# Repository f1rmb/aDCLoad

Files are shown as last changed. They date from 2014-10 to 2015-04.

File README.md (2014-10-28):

Arduino Programmable Constant Current Power Resistance Load
===========================================================

This is all of the code, datasheets and design files for [my instructable](http://www.instructables.com/id/Arduino-Programmable-Constant-Current-Power-Resist/ "Arduino Programmable Constant Current Power Resistance Load") 

* Arduino - It contains the Arduino code that we will be talking about here, within the dummy load folder. It also contains all of the 3rd party libraries I have used.
* Datasheets - It contains all of the datasheets for the major components used within the project.
* DesignSpark - I have used the opensource schematic and PCB design software for this project, its a fantastic free tool that has no limitations and I find it easier to uses than Eagle - http://www.rs-online.com/designspark/electronics/eng/page/designspark-pcb-home-page The rev 1 folder contains all of my initial designs, please don't use this as there are 2 or 3 errors in the footprints plus I have completely revised the layout for rev 2, please only use these files. the gerber files are in there should you wish to have your own board done. See the next step for more information on this.
* LTSpice - This contains all of the LtSpice files from simulating the operation of the MOSFET.

Please checkout my instructable as it describes all of this code and the operation of the dummy load.

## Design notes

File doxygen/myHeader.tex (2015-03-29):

\documentclass[twoside]{book}

% Packages required by doxygen
\usepackage{calc}
\usepackage{doxygen}
\usepackage{graphicx}
\usepackage[utf8]{inputenc}
\usepackage{makeidx}
\usepackage{multicol}
\usepackage{multirow}
\usepackage{textcomp}
\usepackage[table]{xcolor}

% Font selection
\usepackage[T1]{fontenc}
\usepackage{mathptmx}
\usepackage[scaled=.90]{helvet}
\usepackage{courier}
\usepackage{amssymb}
\usepackage{sectsty}
\renewcommand{\familydefault}{\sfdefault}
\allsectionsfont{%
  \fontseries{bc}\selectfont%
  \color{darkgray}%
}
\renewcommand{\DoxyLabelFont}{%
  \fontseries{bc}\selectfont%
  \color{darkgray}%
}

% Page & text layout
\usepackage{geometry}
\geometry{%
  a4paper,%
  top=2.5cm,%
  bottom=2.5cm,%
  left=2.5cm,%
  right=2.5cm%
}
\tolerance=750
\hfuzz=15pt
\hbadness=750
\setlength{\emergencystretch}{15pt}
\setlength{\parindent}{0cm}
\setlength{\parskip}{0.2cm}
\makeatletter
\renewcommand{\paragraph}{%
  \@startsection{paragraph}{4}{0ex}{-1.0ex}{1.0ex}{%
    \normalfont\normalsize\bfseries\SS@parafont%
  }%
}
\renewcommand{\subparagraph}{%
  \@startsection{subparagraph}{5}{0ex}{-1.0ex}{1.0ex}{%
    \normalfont\normalsize\bfseries\SS@subparafont%
  }%
}
\makeatother

% Headers & footers
\usepackage{fancyhdr}
\pagestyle{fancyplain}
\fancyhead[LE]{\fancyplain{}{\bfseries\thepage}}
\fancyhead[CE]{\fancyplain{}{}}
\fancyhead[RE]{\fancyplain{}{\bfseries\leftmark}}
\fancyhead[LO]{\fancyplain{}{\bfseries\rightmark}}
\fancyhead[CO]{\fancyplain{}{}}
\fancyhead[RO]{\fancyplain{}{\bfseries\thepage}}
\fancyfoot[LE]{\fancyplain{}{}}
\fancyfoot[CE]{\fancyplain{}{}}
\fancyfoot[RE]{\fancyplain{}{\bfseries\scriptsize User and Programmer Manual for aDCLoad 2.\-6, written by F1RMB Daniel Caujolle-Bert \copyright 2014-2015 }}
\fancyfoot[LO]{\fancyplain{}{\bfseries\scriptsize User and Programmer Manual for aDCLoad 2.\-6, written by F1RMB Daniel Caujolle-Bert \copyright 2014-2015 }}
\fancyfoot[CO]{\fancyplain{}{}}
\fancyfoot[RO]{\fancyplain{}{}}
\renewcommand{\footrulewidth}{0.4pt}
\renewcommand{\chaptermark}[1]{%
  \markboth{#1}{}%
}
\renewcommand{\sectionmark}[1]{%
  \markright{\thesection\ #1}%
}

% Indices & bibliography
\usepackage{natbib}
\usepackage[titles]{tocloft}
\setcounter{tocdepth}{3}
\setcounter{secnumdepth}{5}
\makeindex

% Hyperlinks (required, but should be loaded last)
\usepackage{ifpdf}
\ifpdf
  \usepackage[pdftex,pagebackref=true]{hyperref}
\else
  \usepackage[ps2pdf,pagebackref=true]{hyperref}
\fi
\hypersetup{%
  colorlinks=true,%
  linkcolor=blue,%
  citecolor=blue,%
  unicode%
}

% Custom commands
\newcommand{\clearemptydoublepage}{%
  \newpage{\pagestyle{empty}\cleardoublepage}%
}

%===== C O N T E N T S =====

\begin{document}

% Titlepage & ToC
\hypersetup{pageanchor=false}
\pagenumbering{roman}
\begin{titlepage}
\vspace*{7cm}
\begin{center}%
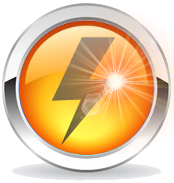
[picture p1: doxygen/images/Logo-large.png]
{}\\
\vspace*{0.5cm}
{\Large Manual for a\-D\-C\-Load \\[1ex]\large version 2.\-6 }\\
\vspace*{1cm}
{\large Written by F1RMB, Daniel Caujolle-Bert \copyright 2014-2015 }\\
\vspace*{1cm}
\end{center}
\end{titlepage}
\clearemptydoublepage
\tableofcontents
\clearemptydoublepage
\pagenumbering{arabic}
\hypersetup{pageanchor=true}

%--- Begin generated contents ---
\chapter{Arduino Programmable Constant Current Power Resistance Load}
\label{mainpage}
\hypertarget{mainpage}{}
\input{mainpage}
\chapter{A\-Tmega32\-U4 fuses settings}
\label{fuses}
\hypertarget{fuses}{}
\input{fuses}
\chapter{Hardware modifications for version 2.6}
\label{mods26}
\hypertarget{mods26}{}
\input{mods26}
\chapter{User interface overview}
\label{gui}
\hypertarget{gui}{}
\input{gui}
\chapter{Remote Commands}
\label{remote}
\hypertarget{remote}{}
\input{remote}
\chapter{Logging data format}
\label{logging}
\hypertarget{logging}{}
\input{logging}
\chapter{Calibration Process}
\label{calibration}
\hypertarget{calibration}{}
\input{calibration}
\chapter{Hierarchical Index}
\input{hierarchy}
\chapter{Class Index}
\input{annotated}
\chapter{File Index}
\input{files}
\chapter{Class Documentation}
\input{uniona_d_c_settings_1_1__eeprom_calibration_value__t}
\input{classa_d_c_display}
\input{classa_d_c_engine}
\input{classa_d_c_settings}
\input{classa_input_relay}
\input{classa_l_c_d}
\input{classa_stepper}
\input{structa_d_c_settings_1_1_calibration_data__t}
\chapter{File Documentation}
\input{a_d_c_load_8cpp}
\input{a_d_c_load_8h}
\input{_c_d_c_8cpp}
\input{_hardware_serial_8cpp}
\input{_h_i_d_8cpp}
\input{_i_p_address_8cpp}
\input{libraries_8cpp}
\input{main_8cpp}
\input{new_8cpp}
\input{_print_8cpp}
\input{sketch_8cpp}
\input{_stream_8cpp}
\input{_tone_8cpp}
\input{_u_s_b_core_8cpp}
\input{_w_interrupts_8c}
\input{wiring_8c}
\input{wiring__analog_8c}
\input{wiring__digital_8c}
\input{wiring__pulse_8c}
\input{wiring__shift_8c}
\input{_w_math_8cpp}
\input{_w_string_8cpp}
%--- End generated contents ---

% Index
\newpage
\phantomsection
\addcontentsline{toc}{chapter}{Index}
\printindex

\end{document}

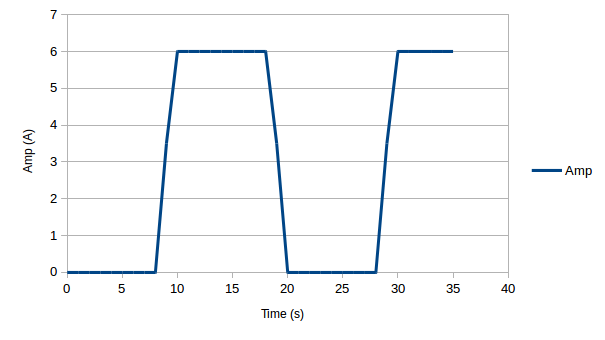
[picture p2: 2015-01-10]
doxygen/images/aDCLoad-Pulse.png

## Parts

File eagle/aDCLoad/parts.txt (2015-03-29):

Partlist

Exported from InputSwitch.brd at 10/02/15 17:02

EAGLE Version 6.1.0 Copyright (c) 1988-2012 CadSoft

Assembly variant: 

Part     Value              Package   Library                    Position (mm)         Orientation

C1       100nF              C0805     resistor                   (45.007634375 17.60451875) R270
D1                          SOD-123   adafruit                   (13.97 15.1765)       R90
H1       MOUNT-PAD-ROUND3.0 3,0-PAD   holes                      (-21.169 34.279)      R0
H2       MOUNT-PAD-ROUND3.0 3,0-PAD   holes                      (43.84 34.279)        R0
JP1      CTRL_PANEL         1X04      SparkFun-Connectors        (2.9381625 17.714425) R270
JP2      MCU                1X05      SparkFun-Connectors        (42.53510625 18.424425) R270
R1       10K                R0805     resistor                   (23.6855 16.9545)     R90
R2       10K                R0805     resistor                   (33.2105 14.224)      R90
R3       1k                 R0805     resistor                   (8.128 15.1765)       R0
R4       10k                R0805     resistor                   (44.96789375 11.736628125) R270
T1       PN2222             SOT23-3   SparkFun-DiscreteSemi      (28.067 16.0655)      R90
T2       PN2222             SOT23-3   SparkFun-DiscreteSemi      (19.558 17.018)       R90
U$1      RELAYPTH2          RELAY-T9A SparkFun-Electromechanical (24.13 13.97)         MR90

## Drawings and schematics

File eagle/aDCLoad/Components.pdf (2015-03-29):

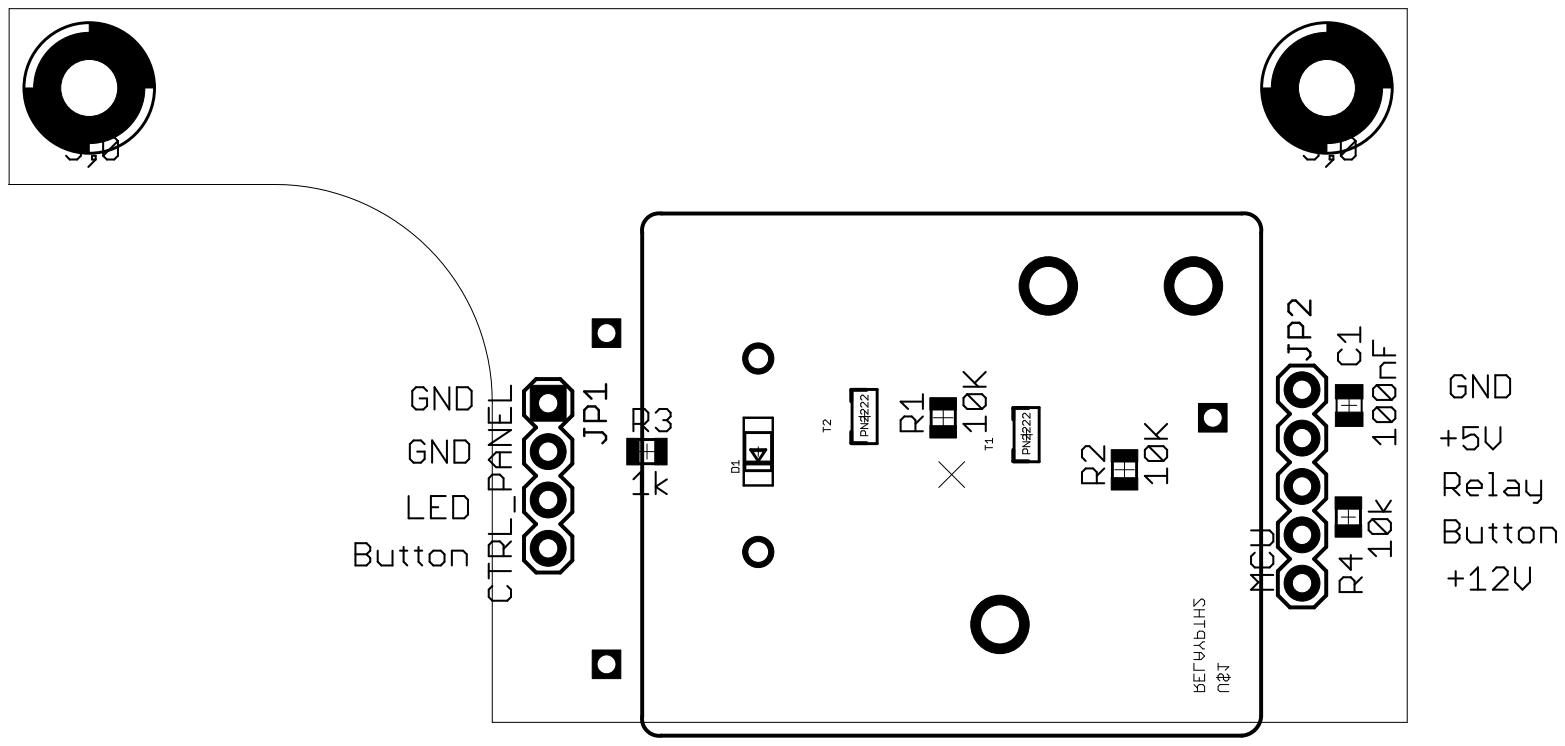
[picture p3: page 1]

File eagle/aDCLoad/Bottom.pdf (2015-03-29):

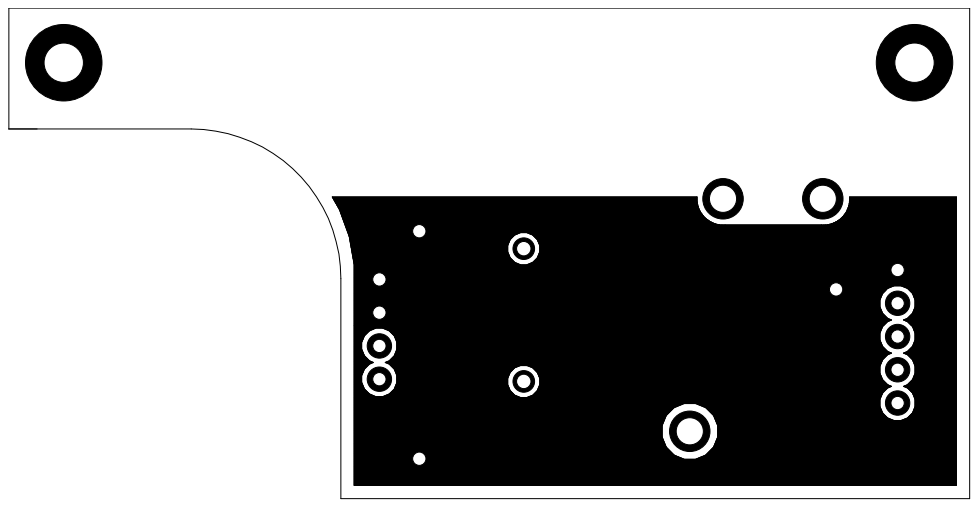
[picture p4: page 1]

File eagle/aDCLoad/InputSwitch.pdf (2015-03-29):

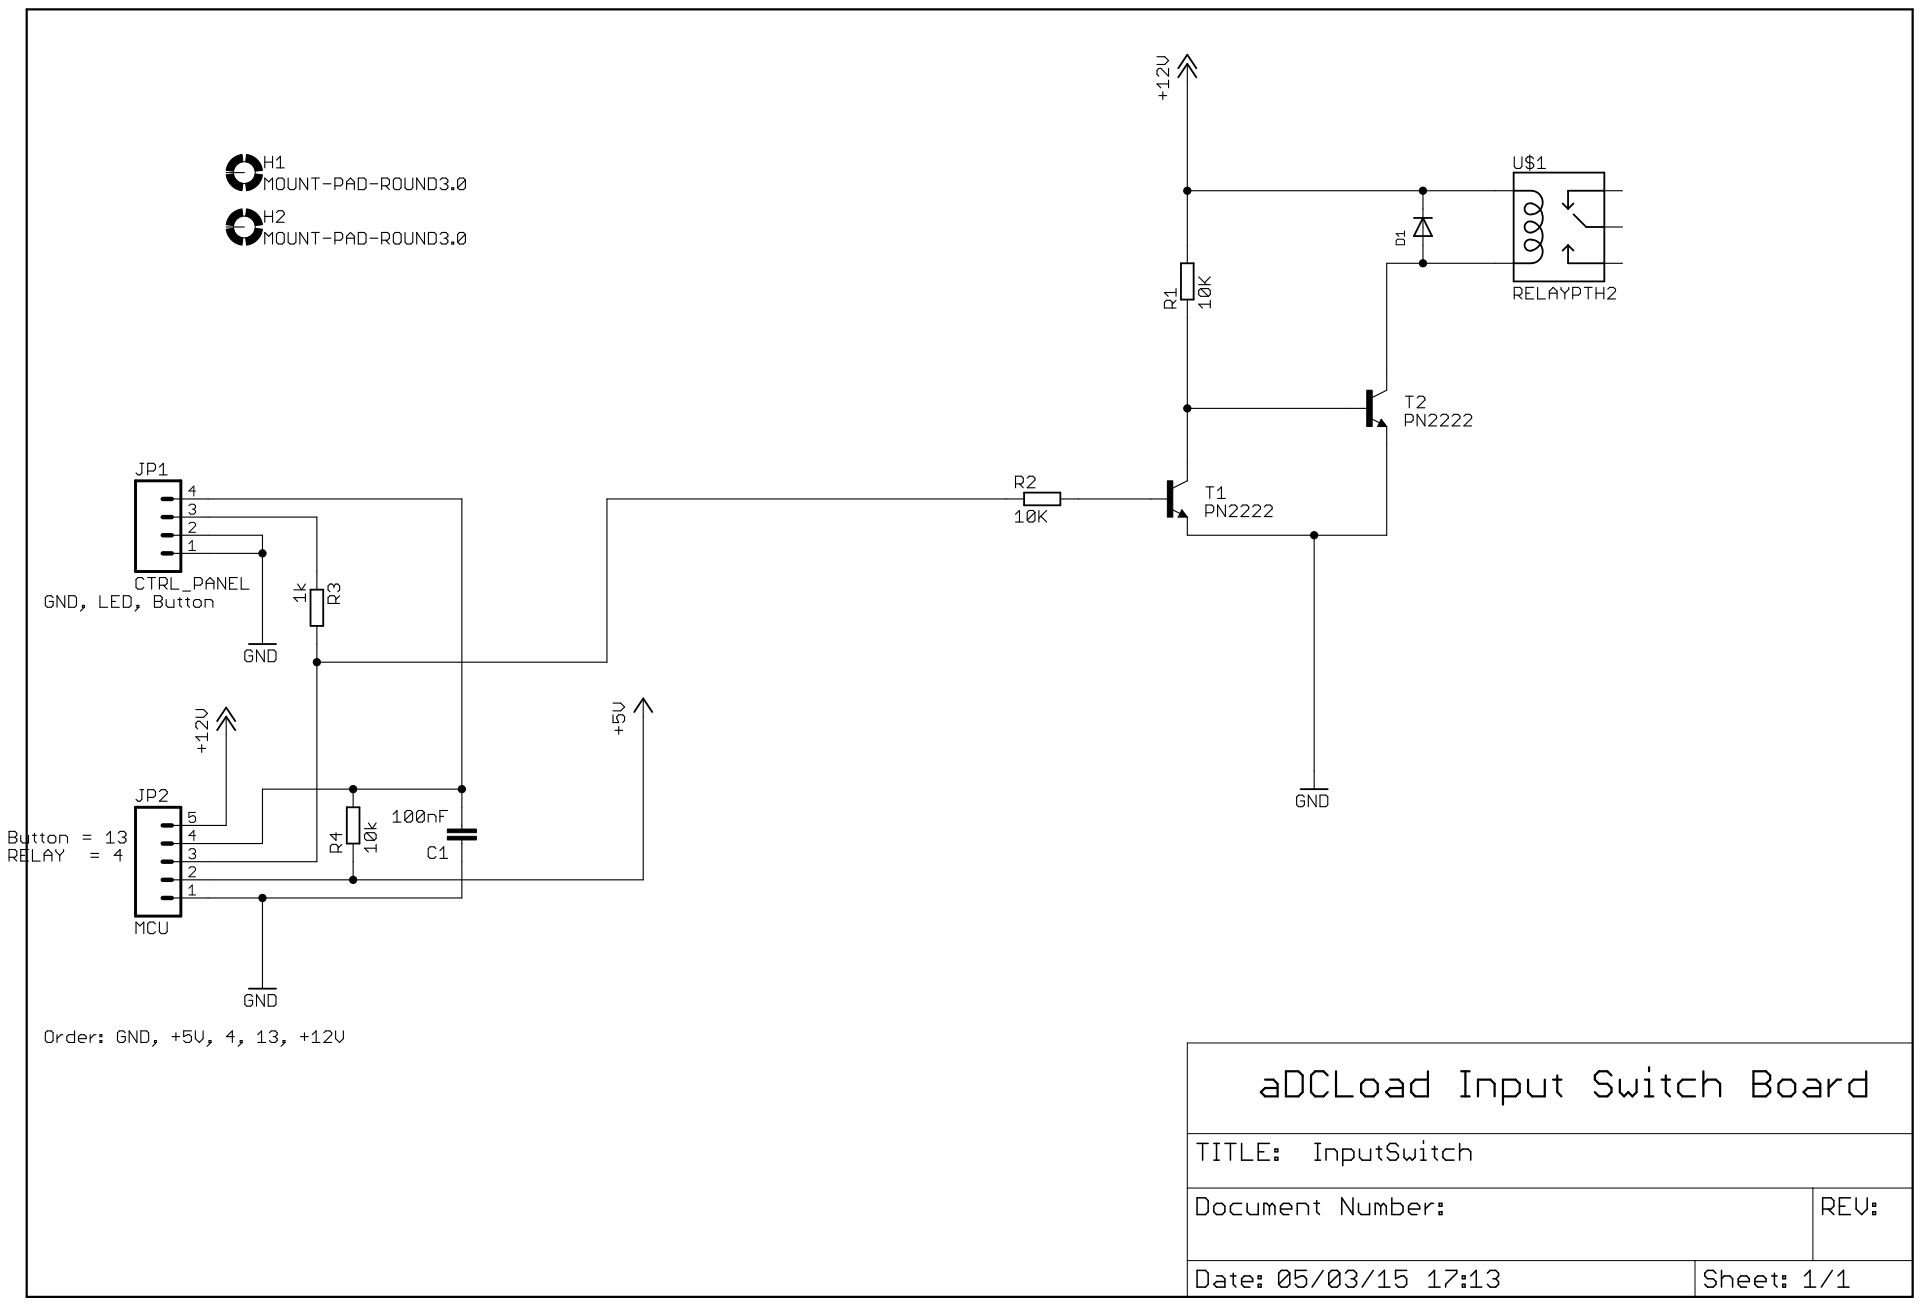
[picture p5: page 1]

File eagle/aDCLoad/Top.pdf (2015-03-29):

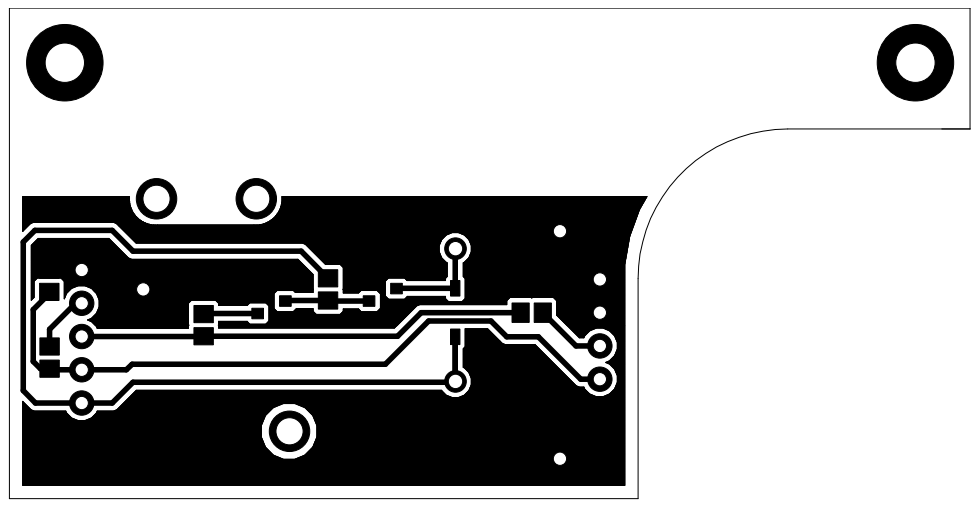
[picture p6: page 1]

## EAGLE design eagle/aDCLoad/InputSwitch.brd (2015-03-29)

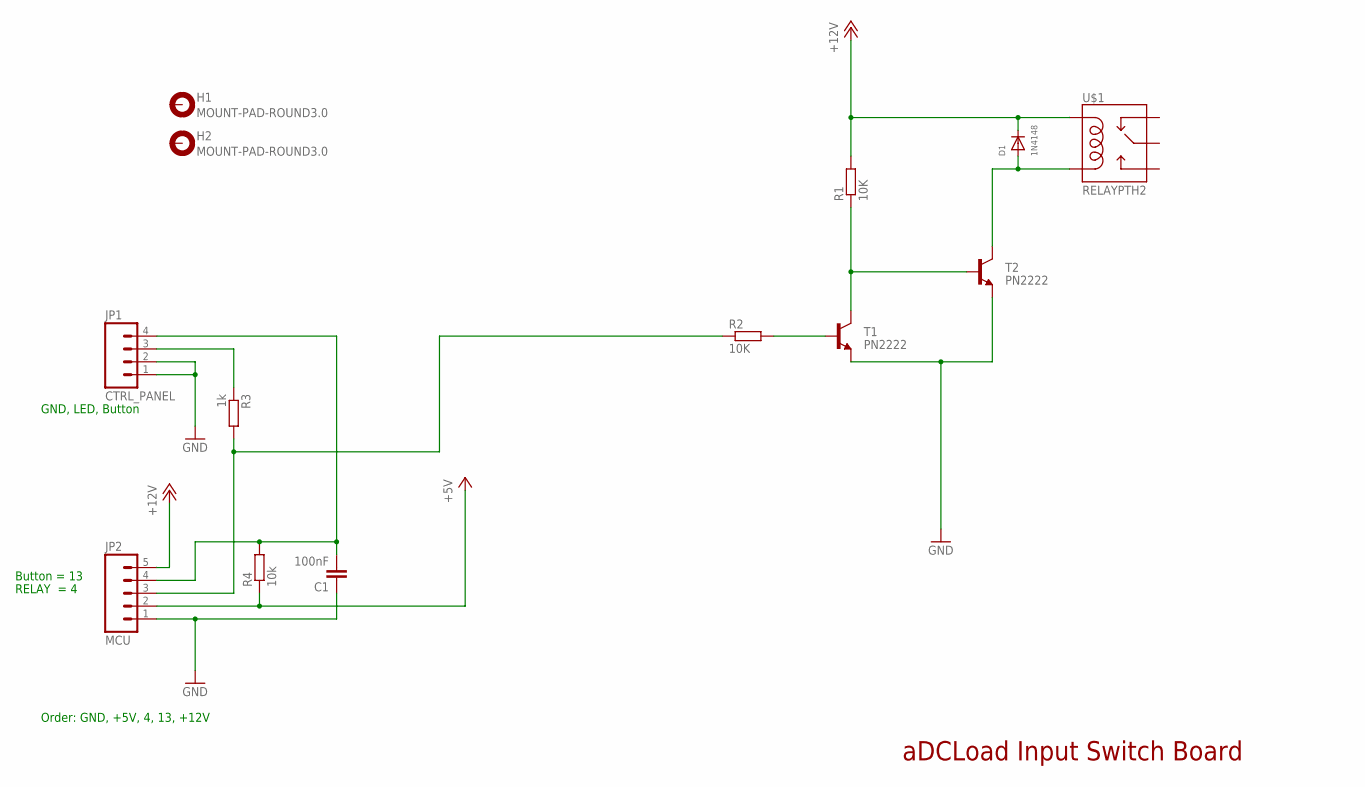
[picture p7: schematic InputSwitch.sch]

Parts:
C1: 100nF; C0805
D1: 1N4148; SOD-123
H1, H2: MOUNT-PAD-ROUND3.0; 3,0-PAD
JP1: CTRL_PANEL; 1X04
JP2: MCU; 1X05
R1, R2: 10K; R0805
R3: 1k; R0805
R4: 10k; R0805
T1, T2: PN2222; SOT23-3
U$1: RELAYPTH2; RELAY-T9A

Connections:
+5V: JP2.2, R4.1
+12V: D1.C, JP2.5, R1.2, U$1.COIL1
BTN: C1.2, JP1.4, JP2.4, R4.2
GND: C1.1, JP1.1, JP1.2, JP2.1, T1.2 (E), T2.2 (E)
unnamed: R2.2, T1.1 (B)
unnamed: R1.1, T1.3 (C), T2.1 (B)
unnamed: D1.A, T2.3 (C), U$1.COIL2
unnamed: JP2.3, R2.1, R3.2
RL_LED: JP1.3, R3.1

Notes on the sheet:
Button = 13
RELAY = 4
Order: GND, +5V, 4, 13, +12V
GND, LED, Button
aDCLoad Input Switch Board

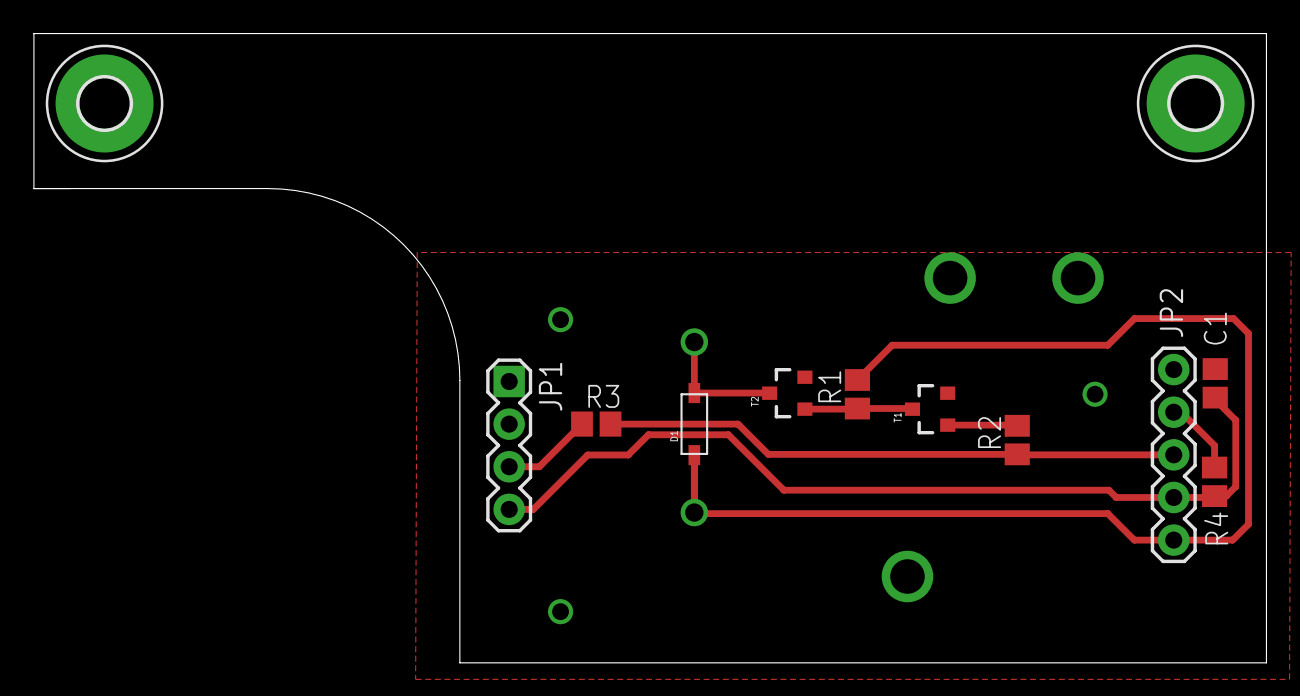
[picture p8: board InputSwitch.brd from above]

Board: 2 copper layers, 73.5 x 37.5 mm, 13 parts (1 on the bottom side), 9 nets.

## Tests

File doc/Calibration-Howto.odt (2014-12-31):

aDCLoad Calibration

Prerequisites:

Hardware:

- Amp-meter,
- Volt-meter,
- Power supply (0..24V, 8A)

Software:

- A serial terminal emulator (eg: “HyperTerminal” or “Tera Term” on Windows, “minicom” or “cutecom” on Linux).

The communication settings are: 57600, 8, N, 1

Process Description

Step 1: Maximum Current

Select “Step 1” tab in the calibration spreadsheet file.

Connect the amp-meter and the power supply to the DC load, for current measurements.

Open your serial terminal emulator, connect the DC load, then type:

:DAC:4095

Write down the mA value readed on the amp-meter to the “mAmax” column.

Now, type:

:DAC:0

Edit the aDCLoad.h source file, browse down the file, looking for the following line:

static const float CURRENT_MAXIMUM = 7.845; ///< Maximum value of load current (A)

If necessary, change the 7.845 value to the one you've got on your amp-meter (don't forget to convert it from mA to A), then reflash the board with new code (using Code::Blocks IDE or the provided Makefile, running “make burn” command).

Remember, if you have to reflash the board, that could be only done using ICSP programming. There is no bootloader flashed on the MCU, due to flash space restriction.

Calibration step 1 is now done.

Step 2: Voltage

Select “Step 2” tab in the calibration spreadsheet file.

Connect your power supply to the DC load, sets to 0V. The DC Load should the sets to 0mA.

In the serial terminal emulator, type:

:CAL:ON

Set your power supply voltage output for each value in “Vset” column, and write down the readed value in “Vread” column.

Once you went through the whole array, the calibration string should be entered into the serial terminal emulator, like:

:CAL:V:x.xxx,y.yyy

Please note that the decimal separator HAS TO BE a period ('.'), as in US format.

Calibration step 2 is now done.

Step 3: Current

Select “Step 3” tab in the calibration spreadsheet file.

Connect the amp-meter and the power supply to the DC load, for current measurements.

Sets the output voltage to 5V.

Using the DAC command, try to adjust its value to match each value in the “A Amp-Meter” column, and write down the readed value, on the LCD or serial terminal emulator output, into the “A LCD/Term.” column.

You can change the values in the “A Amp-Meter” column to strictly match the ones you're reading on the amp-meter.

The DAC command syntax is :

:DAC:value where value is an integer from 0 to 4095.

Once you went through the whole array, set DAC value to 0:

:DAC:0

The calibration string should be entered into the serial terminal emulator, like:

:CAL:C:x.xxx,y.yyy

Please note that the decimal separator HAS TO BE a period ('.'), as in US format.

Calibration step 3 is now done.

Step 4: DAC

Select “Step 4” tab in the calibration spreadsheet file.

Connect the amp-meter and the power supply to the DC load, for current measurements.

Sets the output voltage to 5V.

Set the DAC value for each value in “Steps” column, and write down the readed value on the amp-meter into the “mAread” column.

The DAC command syntax is :

:DAC:value where value is an integer from 0 to 4095.

Once you went through the whole array, set DAC value to 0:

:DAC:0

The calibration string should be entered into the serial terminal emulator, like:

:CAL:D:x.xxx,y.yyy

Please note that the decimal separator HAS TO BE a period ('.'), as in US format.

Calibration step 4 is now done.

Step 5: Voltage Drop

Select “Step 5” tab in the calibration spreadsheet file.

Connect the amp-meter, the volt-meter and the power supply to the DC load, for current AND voltage measurements.

Sets the output voltage to 5V (the last entry in the array should be set around 12V).

Using the DAC command, try to adjust the its value to match each value in the “mA” column on the amp-meter, and write down the voltage readed value on the volt-meter into the “mV meter” column, and the readed value on the LCD and/or serial terminal emulator to the “mV LCD/Term.” column.

The DAC command syntax is :

:DAC:value where value is an integer from 0 to 4095.

You can change the values in the “mA” column to strictly match the ones you're reading on the amp-meter.

For the last row on the array, set the output voltage to around 12V.

Once you went through the whole array, set DAC value to 0:

:DAC:0

The calibration string should be entered into the serial terminal emulator, like:

:CAL:VD:x.xxx,y.yyy

Please note that the decimal separator HAS TO BE a period ('.'), as in US format.

Calibration step 5 is now done.

Last Step: Backup

Once the full calibration is done, you HAVE to save the values into the EEPROM, using the following command:

:CAL:SAVE

Now, the calibration is done, and you can use your DC load.

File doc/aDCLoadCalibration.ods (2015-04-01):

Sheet: Step 1
Maximum Current Calibration
Set Voltage Source to 5V / >=8A
 |  | DAC | mAmax
 |  | 4095 | 7845
 | static const float CURRENT_MAXIMUM = |  |  | 7,845;

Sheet: Step 2
Voltage Calibration Step
Set Current to 0mA
 | Vset | Vread LCD/Term.
 | 0,1 | 0,0055
 | 0,2 | 0,014
 | 0,5 | 0,039
 | 1 | 0,0805
 | 2 | 0,1635
 | 3 | 0,247
 | 4 | 0,33
 | 5 | 0,4135
 | 6 | 0,496
 | 7 | 0,5795
 | 8 | 0,6625
 | 9 | 0,746
 | 10 | 0,8295
 | 11 | 0,9125
 | 12 | 0,9955
 | 13 | 1,079
 | 14 | 1,1625
 | 15 | 1,2455
 | 16 | 1,3285
 | 17 | 1,4115 | Slope = | 12,0164739328 |  | Offset = | 0,0341809174
 | 18 | 1,4955
 | 19 | 1,5785 | Calibration String = |  | :CAL:V:12,0164739328,0,0341809174
 | 20 | 1,6615
 | 21 | 1,745
 | 22 | 1,8275
 | 23 | 1,9115
 | 24 | 1,9945
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

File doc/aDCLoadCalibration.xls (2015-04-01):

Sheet: Step 1
Maximum Current Calibration
Set Voltage Source to 5V / >=8A
 |  | DAC | mAmax
 |  | 4095 | 7845
 | static const float CURRENT_MAXIMUM = |  |  | 7,845;

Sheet: Step 2
Voltage Calibration Step
Set Current to 0mA
 | Vset | Vread LCD/Term.
 | 0.1 | 0.0055
 | 0.2 | 0.014
 | 0.5 | 0.039
 | 1 | 0.0805
 | 2 | 0.1635
 | 3 | 0.247
 | 4 | 0.33
 | 5 | 0.4135
 | 6 | 0.496
 | 7 | 0.5795
 | 8 | 0.6625
 | 9 | 0.746
 | 10 | 0.8295
 | 11 | 0.9125
 | 12 | 0.9955
 | 13 | 1.079
 | 14 | 1.1625
 | 15 | 1.2455
 | 16 | 1.3285
 | 17 | 1.4115 | Slope = | 12.01647393 |  | Offset = | 0.03418091738
 | 18 | 1.4955
 | 19 | 1.5785 | Calibration String = |  | 0
 | 20 | 1.6615
 | 21 | 1.745
 | 22 | 1.8275
 | 23 | 1.9115
 | 24 | 1.9945
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

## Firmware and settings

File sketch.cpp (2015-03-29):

/*

  Copyright (C) 2014-2015  F1RMB, Daniel Caujolle-Bert <f1rmb.daniel@gmail.com>
  Copyright (C) 2014       Lee Wiggins <lee@wigweb.com.au>

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
  You should have received a copy of the GNU General Public License
  along with this program; if not, write to the Free Software
  Foundation, Inc., 51 Franklin Street, Fifth Floor, Boston, MA  02110-1301, USA.
*/

#include <Arduino.h>

#include "aDCLoad.h"

/*
Version Control

1.00
Initial upload

1.10
* Fixed an error in the set current function of the DAC
* Added improved current calculation to allow for correction in OP-AMP offset, uses the measured value to adjust the set current.
* General code tidy up

2.0
* full rewrite, using C++. Lot of bug fixes, lot of new features.
* size of the hex should be:
*      text	   data	    bss	    dec	    hex	filename
*     30884	    206	    506	  31596	   7b6c	output/sketch.elf

To - Dos
* Display in engineering units, ie. mA and mW.

*/

/**
 *                            !!!!! BIG FAT WARNING !!!!!
 *                        Should be compiled with "-Os" flag.
 *                Bootloader couldn't be flashed, ISP programming ONLY
 *            -=- use Code::Blocks or the included Makefile to compile -=-
 *
**/

aDCEngine engine(LCD_RS_PIN, LCD_ENABLE_PIN, LCD_D4_PIN, LCD_D5_PIN, LCD_D6_PIN, LCD_D7_PIN, LCD_COLS_NUM, LCD_ROWS_NUM,
#ifdef HAS_INPUT_RELAY
                 INPUT_RELAY_BUTTON_PIN, INPUT_RELAY_RELAY_PIN,
#endif
                 ENCODER_A_PIN, ENCODER_B_PIN, ENCODER_PB_PIN, ENCODER_STEPS_PER_NOTCH);

void setup()
{
    engine.setup();
}

void loop()
{
    engine.run();
}

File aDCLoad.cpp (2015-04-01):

/**
 *
 * \copyright Copyright (C) 2014-2015  F1RMB, Daniel Caujolle-Bert <f1rmb.daniel@gmail.com>
 * \copyright Copyright (C) 2014       Lee Wiggins <lee@wigweb.com.au>
 *
 * \license
This program is free software; you can redistribute it and/or
modify it under the terms of the GNU General Public License
as published by the Free Software Foundation; either version 2
of the License, or (at your option) any later version.<br><br>
This program is distributed in the hope that it will be useful,
but WITHOUT ANY WARRANTY; without even the implied warranty of
MERCHANTABILITY or FITNESS FOR A PARTICULAR PURPOSE.  See the
GNU General Public License for more details.<br><br>
You should have received a copy of the GNU General Public License
along with this program; if not, write to the Free Software
Foundation, Inc., 51 Franklin Street, Fifth Floor, Boston, MA  02110-1301, USA.
*/

/**
 *
 * \warning
<h1><center> BIG FAT WARNING </center></h1>
<center>Should be compiled with  <b> "-Os" </b> flag.</center>
<center>Bootloader <b><span style="text-decoration:underline;color:red;">couldn't</span></b> be flashed, <b>ISP programming ONLY</b></center>
<center> -=- use <i>Code::Blocks</i> or the included <i>Makefile</i> to compile -=- </center>
*/
#warning !!! BIG FAT WARNING !!!
#warning !!! Should be compiled with "-Os" !!!

#include <Arduino.h>
#include <avr/pgmspace.h>
#include <LiquidCrystal.h>
#include <SPI.h>
#include <EEPROM.h>
#include <ClickEncoder.h>
#include <TimerOne.h>

#ifndef RESISTANCE
#include <TimerThree.h>
#endif

#include "aDCLoad.h"

/** \file aDCLoad.cpp
    \author F1RMB, Daniel Caujolle-Bert <f1rmb.daniel@gmail.com>
    \author Lee Wiggins <lee@wigweb.com.au>
*/

// A bit of user's manual
/**
 * \page mainpage Arduino Programmable Constant Current Power Resistance Load
 *
 * \section origlee Original README.md from Lee Wiggins
 *
 * This is all of the code, datasheets and design files for [my instructable](http://www.instructables.com/id/Arduino-Programmable-Constant-Current-Power-Resist/ "Arduino Programmable Constant Current Power Resistance Load")
 *
 * * Arduino - It contains the Arduino code that we will be talking about here, within the dummy load folder. It also contains all of the 3rd party libraries I have used.
 * * Datasheets - It contains all of the datasheets for the major components used within the project.
 * * DesignSpark - I have used the opensource schematic and PCB design software for this project, its a fantastic free tool that has no limitations and I find it easier to uses than Eagle - http://www.rs-online.com/designspark/electronics/eng/page/designspark-pcb-home-page The rev 1 folder contains all of my initial designs, please don't use this as there are 2 or 3 errors in the footprints plus I have completely revised the layout for rev 2, please only use these files. the gerber files are in there should you wish to have your own board done. See the next step for more information on this.
 * * LTSpice - This contains all of the LtSpice files from simulating the operation of the MOSFET.
 *
 * Please checkout my instructable as it describes all of this code and the operation of the dummy load.
 *
 *
 * \section adddaniel Informations on this code from Daniel Caujolle-Bert
 *
 * \todo write that!
 * \todo notes on Code::Blocks, flashing with avrdude/Makefile, provided HEX file, and so on
 */
#warning WRITE THE STUFF ABOVE
/**
 * \page fuses ATmega32U4 fuses settings
 *
 * Unlike the Arduino&trade; Leornardo board, the ATmega32U4 MCU used in this DC Load needs some special fuses settings.
 *
 * The following command line defines them to the correct values:
 *
 * \code avrdude -F -p atmega32u4 -C /etc/avrdude.conf -v -e -V -c usbasp -P usb -U lfuse:w:0xFF:m -U hfuse:w:0xD1:m -U efuse:w:0xCB:m -F \endcode
 *
 * You can also invoke the provided <i>Makefile</i>, as:
 *
 * \code make fuses \endcode
 *
 */

/** \page mods26 Hardware modifications for version 2.6
 *
 *
 * Since the <b>Pulse Transient Time</b> and the <b>Input Relay</b> features introduction, few small hardware modifications are required:
 *  + The LCD cabling (<b>!!! on the LCD's PCB only !!!</b>) should be modified as below:
 *     * resolder the cable from pins <b>d0</b>, <b>d1</b>, <b>d2</b> and <b>d3</b> to <b>d4</b>, <b>d5</b>, <b>d6</b> and <b>d7</b>, accordingly,
 *  + Build the small input relay PCB (files available with source code),
 *  + Get <b>GND</b> and <b>+5V</b> from the LCD connector (on the DC Load board, first and second pins),
 *    and connect them to the relay's PCB,
 *  + Get the <b>+12V</b> DC from your power supply,
 *  + connect old <b>d4</b> and <b>d5</b> (from the DC Load board LCD connector) to the relay PCB as <b>Relay</b> and <b>Button</b>, accordingly.
 *
 */
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

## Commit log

2014-10-20 Import aDCLoad, the Arduino controlled Constant Current DC Load.
2014-12-04 Log of cleanup, documentation (doxy) added, logging rate fixup. First flash on real leonardo chip.
    [aDCLoad.cpp, aDCLoad.h]
2014-12-06 Fix stupid button pin checking.
2014-12-06 Use 8 pins for LCD since it's already wired (original code use 4 bits mode).
2014-12-21 Implement calibration, values are stored into EEPROM. Update documentation. Code is running on my finaly built DC Load hardware, without bootloader due to flash free space.
    [aDCLoadCalibration.ods]
2014-12-21 Update/cleanup calibration file
    [aDCLoadCalibration.ods]
2014-12-23 Add over-temperature feature. Slow down display update rate. Ready for release this final version (documentation needs to be finished).
2014-12-29 Add voltage drop calibration ':CAL:VD:'. Update fanspeed DAC values. Don't catch OCP while calibrating. Updata malefile for fuses, flash and calibrations. Optimize EEPROM calibration backup/restore.
2014-12-30 Calibration documentations
    [aDCLoadCalibration.ods]
2015-01-06 Add calibration spreadsheet Excel format.
    [aDCLoadCalibration.xls]
2015-01-06 modify burn stage
2015-01-10 Add Pulse Transient Time feature. Use TimerThree. Switch TimerOne version to PJRC one: https://www.pjrc.com/teensy/td_libs_TimerOne.html. Doc also updated.
2015-01-10 Update Makefile for TimerThree lib usage. New HEX.
2015-03-29 Add two mosfets and input relay support
2015-03-29 Add Eagle files for input switch board
    [InputSwitch.brd, InputSwitch.sch]
2015-04-01 Fix fuses flash/documentation. Add F1JKY calibration values. Rebuild html/latex/mdf docs.
    [aDCLoadCalibration.ods, aDCLoadCalibration.xls]

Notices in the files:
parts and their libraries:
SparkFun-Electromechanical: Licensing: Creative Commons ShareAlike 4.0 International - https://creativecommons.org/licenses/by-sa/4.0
